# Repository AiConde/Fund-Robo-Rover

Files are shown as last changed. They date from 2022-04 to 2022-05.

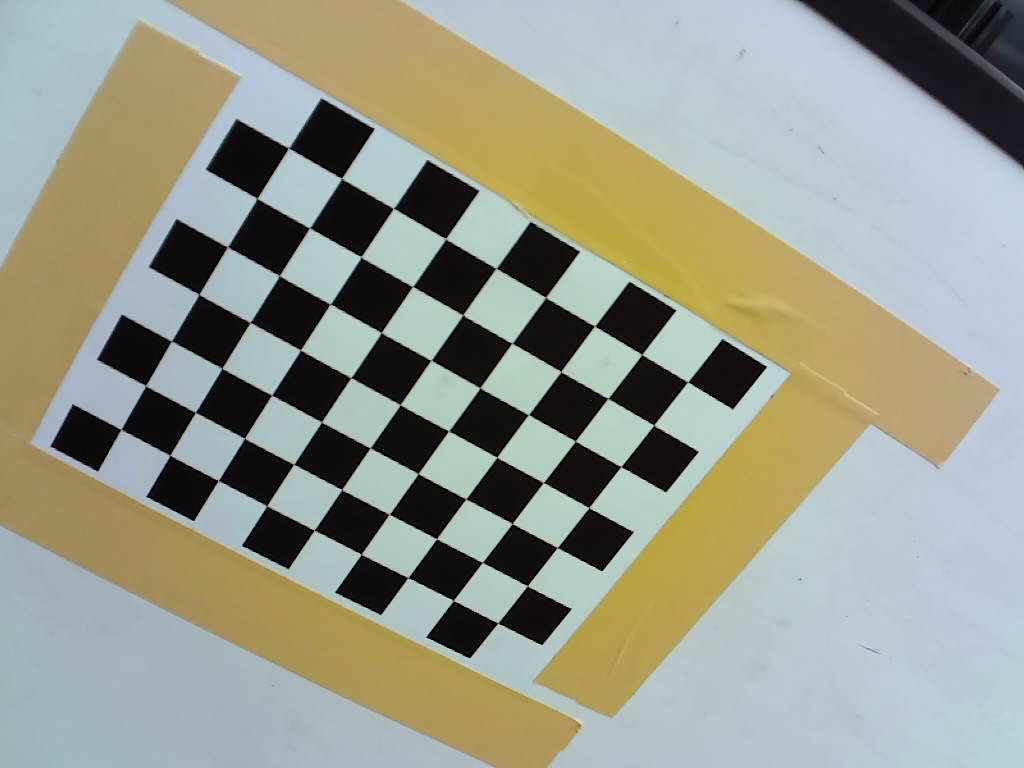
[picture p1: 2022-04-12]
matlab_code/camera_calibration/calib_1024x768/my_photo-11.jpg

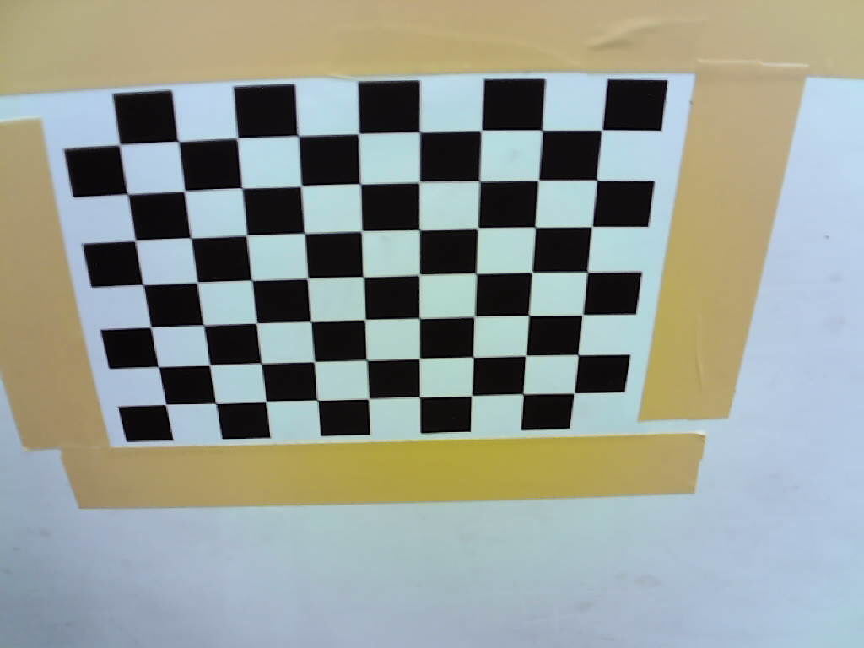
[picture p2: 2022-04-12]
matlab_code/camera_calibration/calib_1024x768/my_photo-2.jpg

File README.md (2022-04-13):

# Fund-Robo-Rover
This repository contains shared files for team 1's final project in Fundamentals of Robotics, Spring 2022.

There are two file categories: CAD files (mostly SOLIDWORKS files) and robot control code (mostly MATLAB files with some ROS mixed in).

The sensor features of the rover are:

LiDAR: 1 Hokuyo URG-005
Sonar: 2 MaxBotix MB1040
Infared: 6 Sharp GP2Y0A02YK0F
Camera: 1 SVPRO 8-megapixel webcam, 5-50 mm focus

Logic is run on an intel NUC running Ubuntu and logic/motor controls are routed through an Arduino Nano connected to a HiLetgo Nano v3.

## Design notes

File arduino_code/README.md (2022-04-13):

Please install "Arduino Mbed OS Nano Boards", "Arduino_LSM9DS1", and "Encoder" in the Arduino library installer.

Attached components:
- Onboard LSM9DS1
- 3x Servos (pan servo, ESC PWM, steering servo)
- 6x Sharp IR (connected to analog pins)
- 2x Sonar (connected to analog pins)
- Hall tacometer (connected to digital pins)

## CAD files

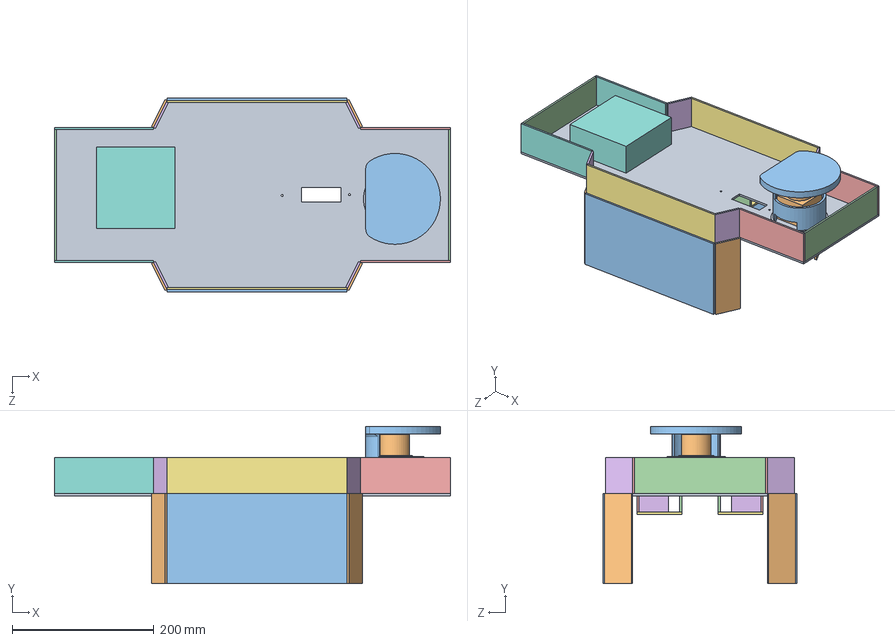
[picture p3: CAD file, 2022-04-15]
CAD files/ShellCAD/ShellAssem.SLDASM
558.8 x 221.9 x 273.0 mm
BasePlate
LowerPanelThin x 4
LowerPanelWide x 2
BatteryCaseShort x 2
BatteryCaseLong x 2
BatteryCaseEnd x 2
NUC
LIDAR_base
LIDAR
LIDAR_top
UpperFront x 2
UpperFrontWall x 2
UpperAngleWallSmall x 4
UpperAngleWallLarge x 2
UpperRearWall x 2
LidarLift

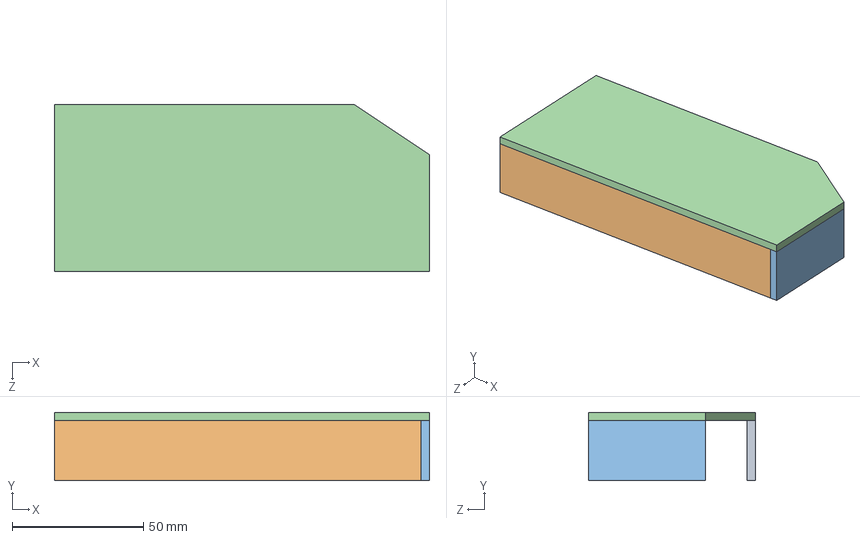
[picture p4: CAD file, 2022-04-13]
CAD files/ShellCAD/BatteryCase/BatteryCaseRAssem.SLDASM
142.9 x 26.0 x 63.5 mm
BatteryCaseShort
BatteryCaseLong
BatteryCaseEnd

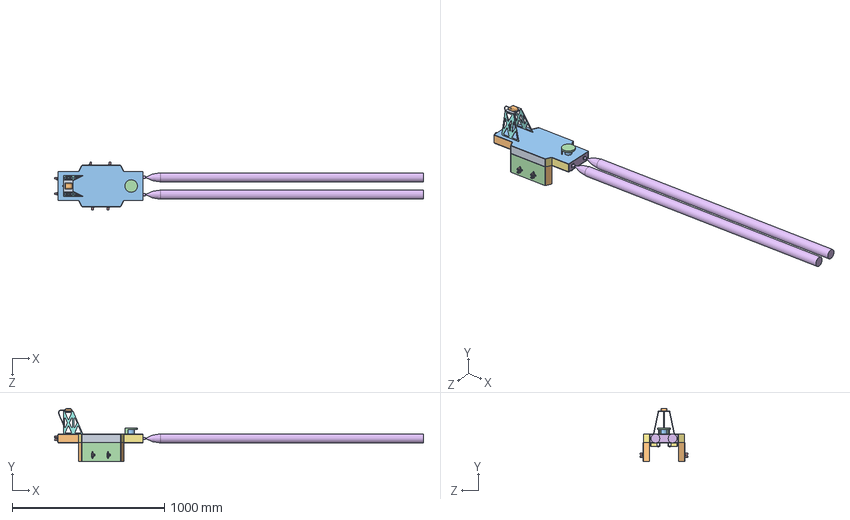
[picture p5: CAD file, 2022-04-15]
CAD files/ShellCAD/WiringHoles/ShellAssem.SLDASM
2425.6 x 350.0 x 316.2 mm
BasePlate
LowerPanelThin x 4
LowerPanelWideLeft
LowerPanelWideRight
BatteryCaseShort x 2
BatteryCaseLong x 2
BatteryCaseEnd x 2
NUC
LIDAR_base
LIDAR
LIDAR_top
UpperRear
UpperFront
UpperFrontWall x 2
UpperAngleWallSmall x 4
UpperAngleWallLarge x 2
UpperRearWall x 2
CoverPlate
LidarLift
OYS-31006 x 6
SENSOR, SONAR, Maxbotix EZ4 x 2
UpperLidCatch x 4
GPSTowerLeg x 2
GPSTowerTop
GPS Antenna

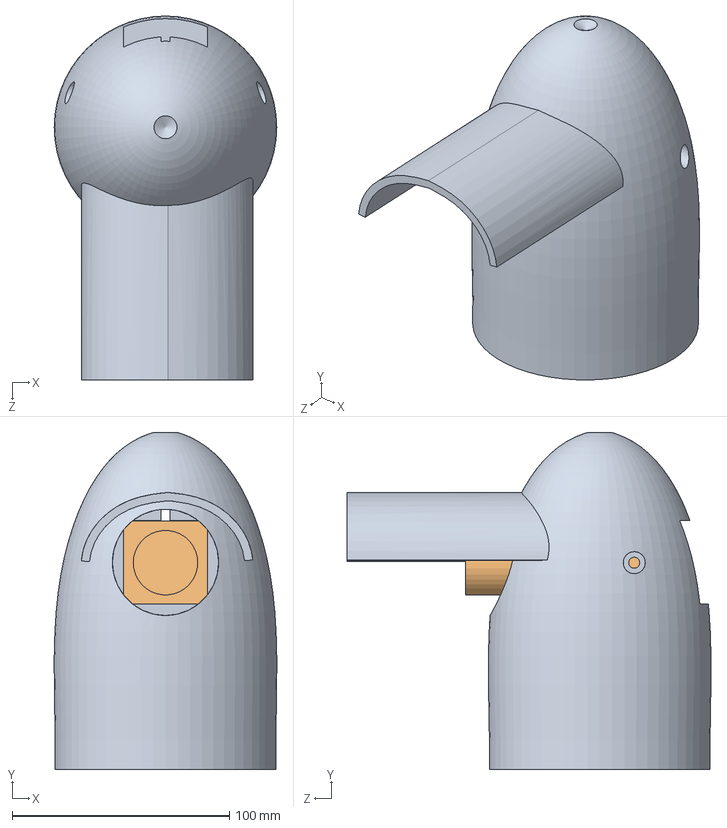
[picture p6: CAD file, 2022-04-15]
CAD files/Assem1.SLDASM
102.5 x 155.3 x 167.6 mm
among_us
camera

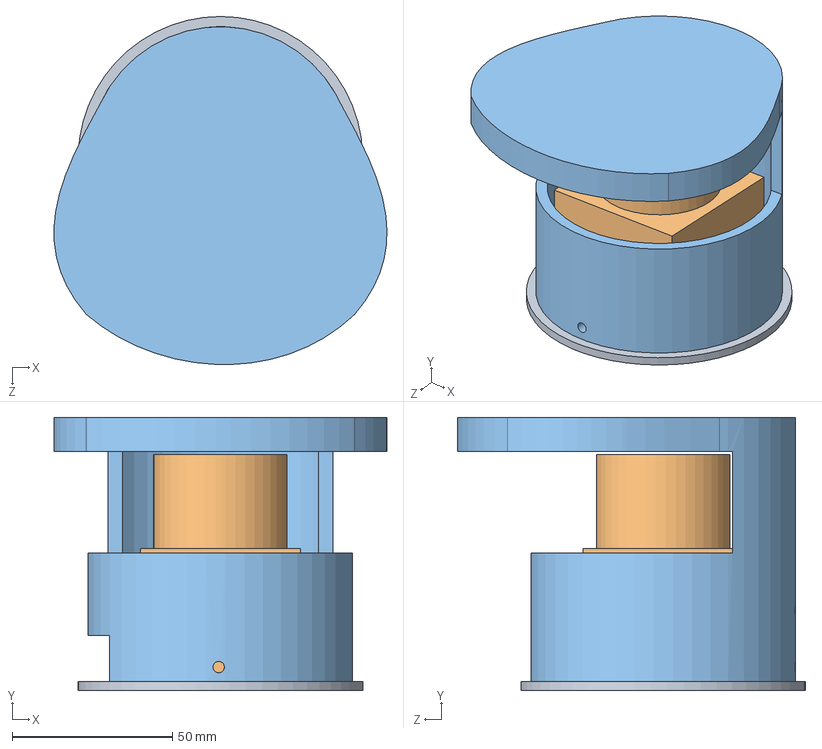
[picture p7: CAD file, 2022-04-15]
CAD files/LIDAR_case.SLDASM
104.0 x 85.3 x 108.7 mm
LIDAR_base
LIDAR
LIDAR_top

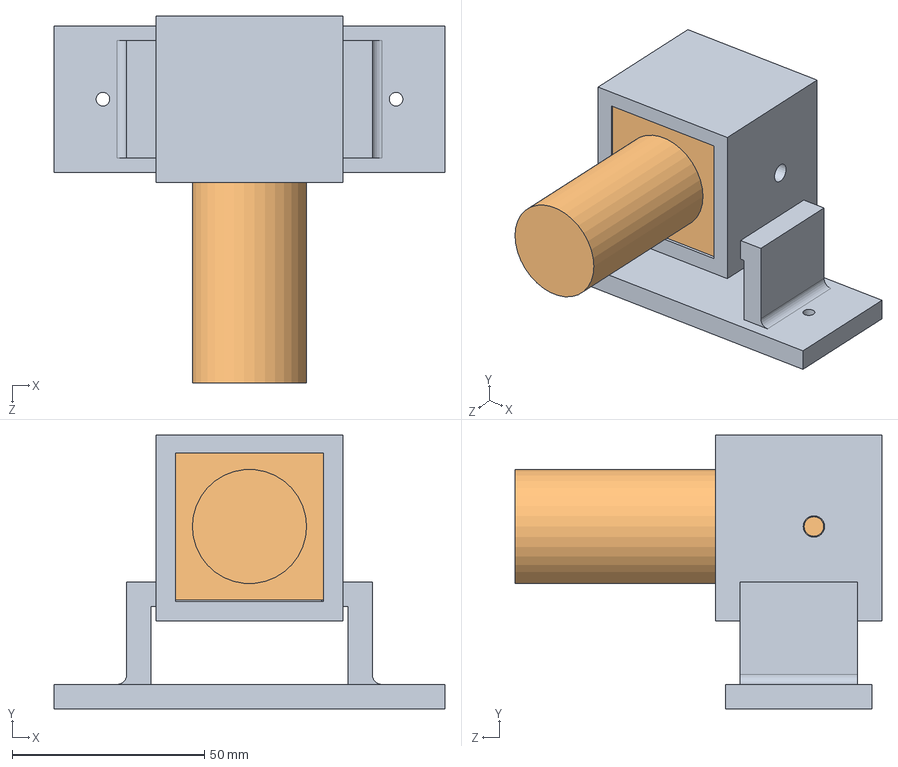
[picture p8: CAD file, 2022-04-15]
CAD files/camer_case.SLDASM
101.6 x 71.2 x 95.5 mm
cam_case
camera

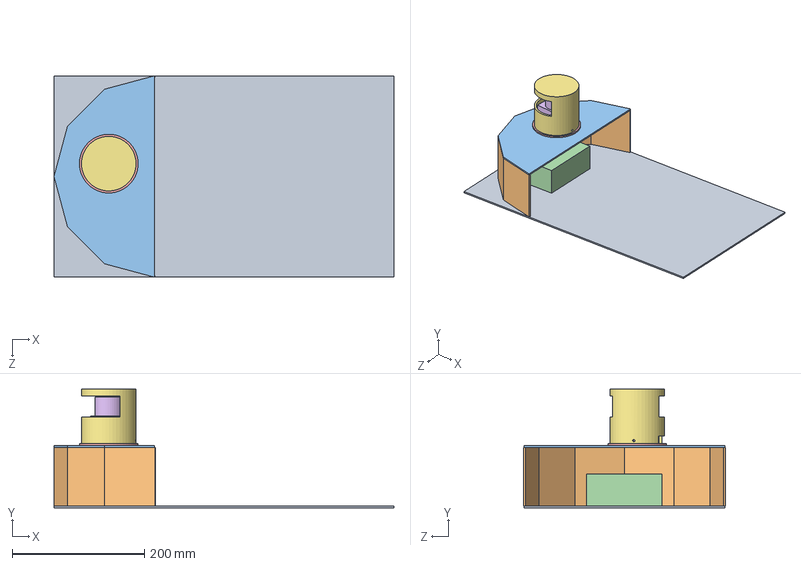
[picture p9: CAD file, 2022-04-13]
CAD files/outershell.SLDASM
514.3 x 179.8 x 304.9 mm
Base
hex_IR x 6
hex_hood
NUC
LIDAR_base
LIDAR
LIDAR_top

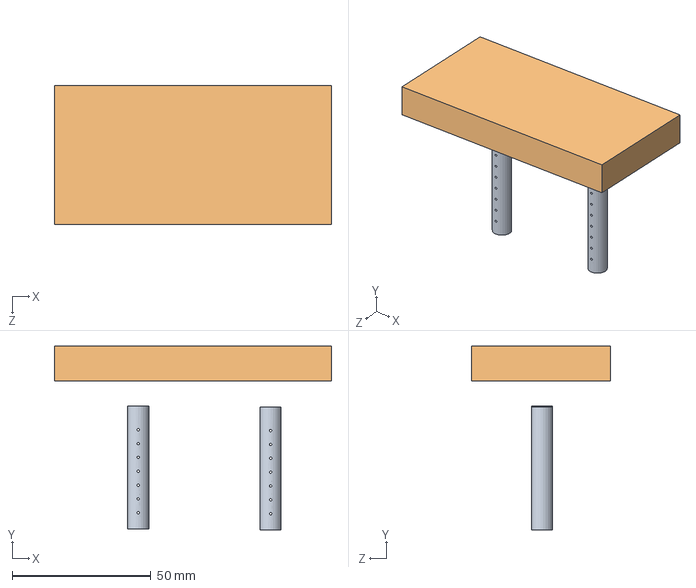
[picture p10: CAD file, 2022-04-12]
CAD files/Attachment.SLDASM
100.0 x 66.4 x 50.0 mm
Attachment Leg x 2
Attachment Plate

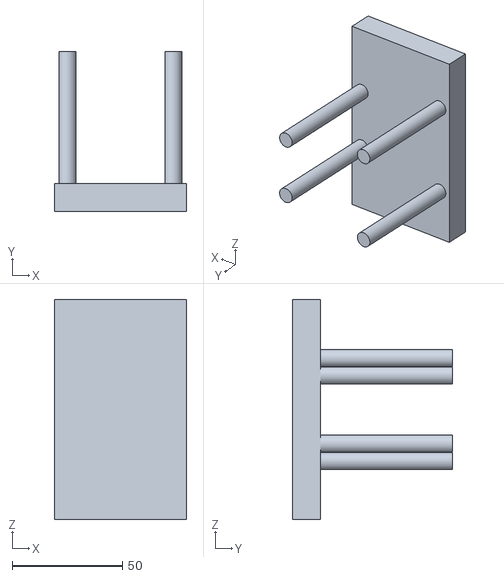
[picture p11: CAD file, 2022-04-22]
CAD files/3D print please/For Dave/Attachment Print.STL
60.0 x 72.7 x 100.0

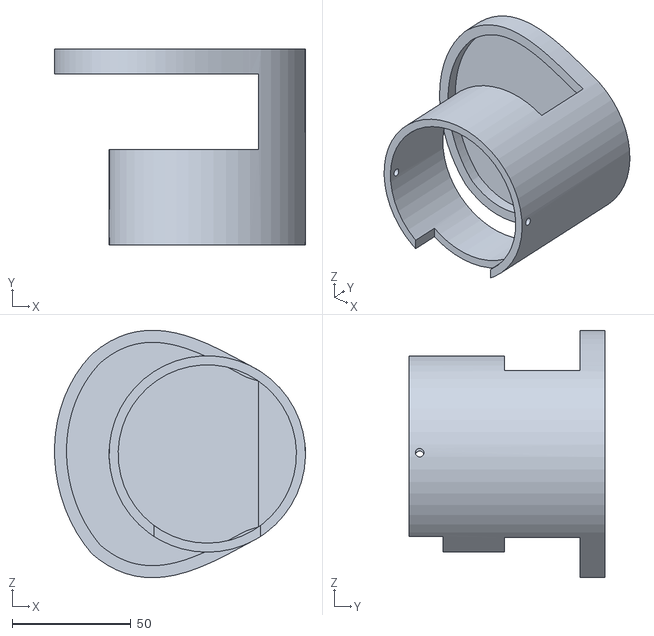
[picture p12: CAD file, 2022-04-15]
CAD files/3D print please/LIDAR_top2-0.STL
105.5 x 82.5 x 104.0

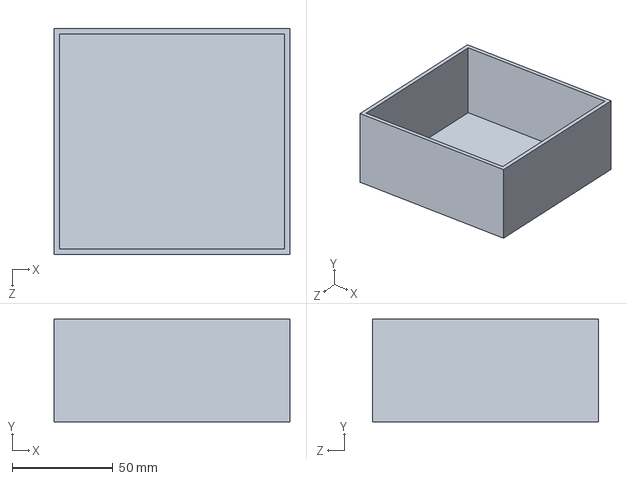
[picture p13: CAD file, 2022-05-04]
CAD files/Nuc Housing Rev 1.SLDPRT
117.3 x 51.1 x 112.5 mm

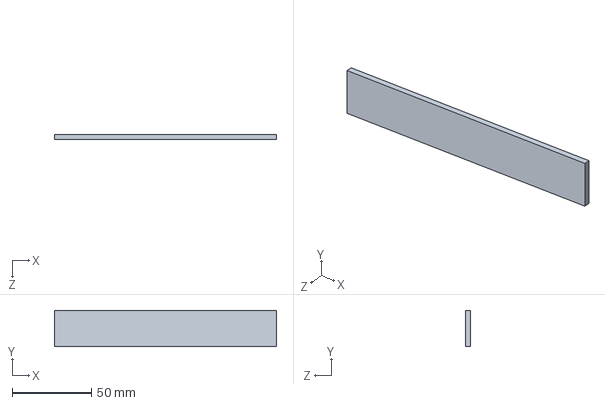
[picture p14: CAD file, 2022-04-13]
CAD files/ShellCAD/BatteryCase/BatteryCaseLong.SLDPRT
139.7 x 22.9 x 3.17 mm

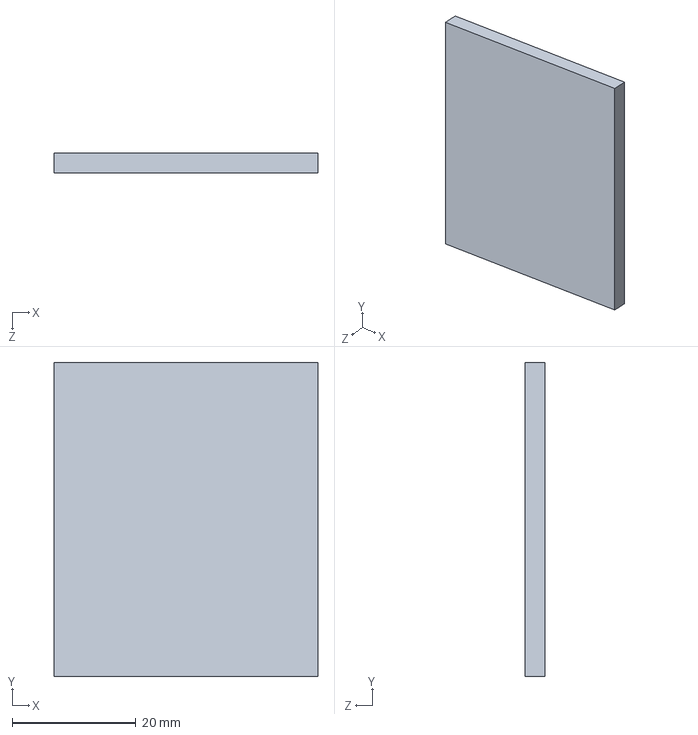
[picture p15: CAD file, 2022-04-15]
CAD files/ShellCAD/WiringHoles/UpperLidCatch.SLDPRT
42.7 x 50.8 x 3.17 mm

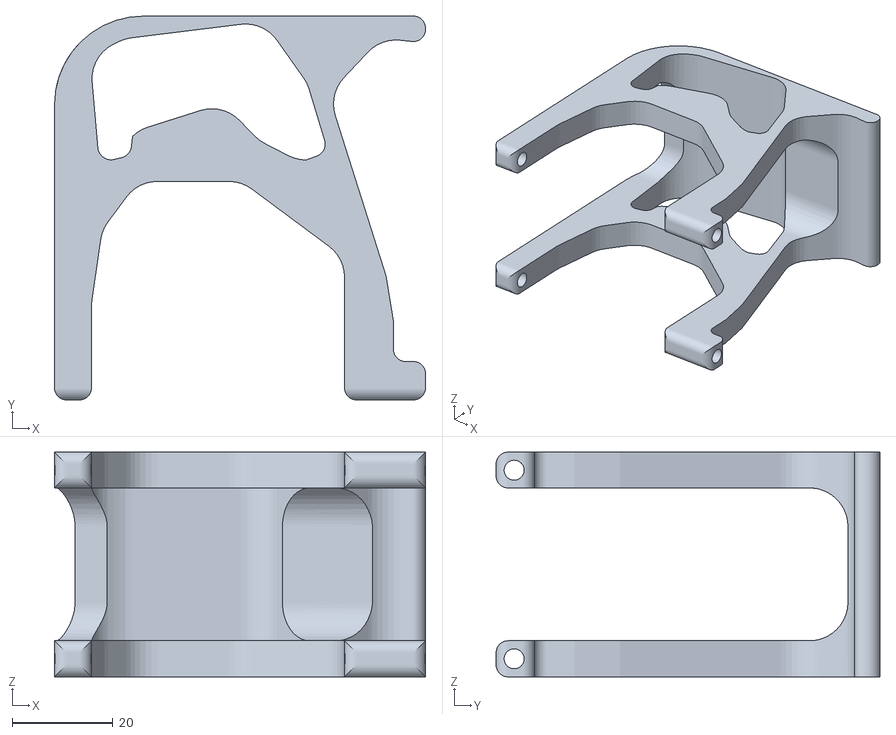
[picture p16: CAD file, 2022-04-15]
CAD files/3D print please/For Dave/frame_adapter.STL
73.7 x 76.2 x 44.6

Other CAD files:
CAD files/ShellCAD/BatteryCase/BatteryCaseLAssem.SLDASM
CAD files/pan_mechanism.SLDASM
CAD files/3D print please/fram adapter.STL
CAD files/Attachment Plate.SLDPRT
CAD files/3D print please/For Dave/Lidar_Case.STL
CAD files/3D print please/For Dave/camera_case.STL
CAD files/3D print please/For Dave/camera_sun-shield.STL
CAD files/3D print please/LIDAR_base.STL
CAD files/3D print please/LIDAR_top.STL
CAD files/3D print please/cam_case.STL
CAD files/Attachment Leg.SLDPRT
CAD files/Base.SLDPRT
CAD files/GPS Antenna.SLDPRT
CAD files/IR.SLDPRT
CAD files/LIDAR.SLDPRT
CAD files/LIDAR_base.SLDPRT
CAD files/LIDAR_top.SLDPRT
CAD files/LIDAR_top_sun.SLDPRT
CAD files/NUC.SLDPRT
CAD files/ShellCAD/BatteryCase/BatteryCaseEnd.SLDPRT
CAD files/ShellCAD/BatteryCase/BatteryCaseShort.SLDPRT
CAD files/ShellCAD/CoverPlate.SLDPRT
CAD files/ShellCAD/WiringHoles/BasePlate.SLDPRT
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

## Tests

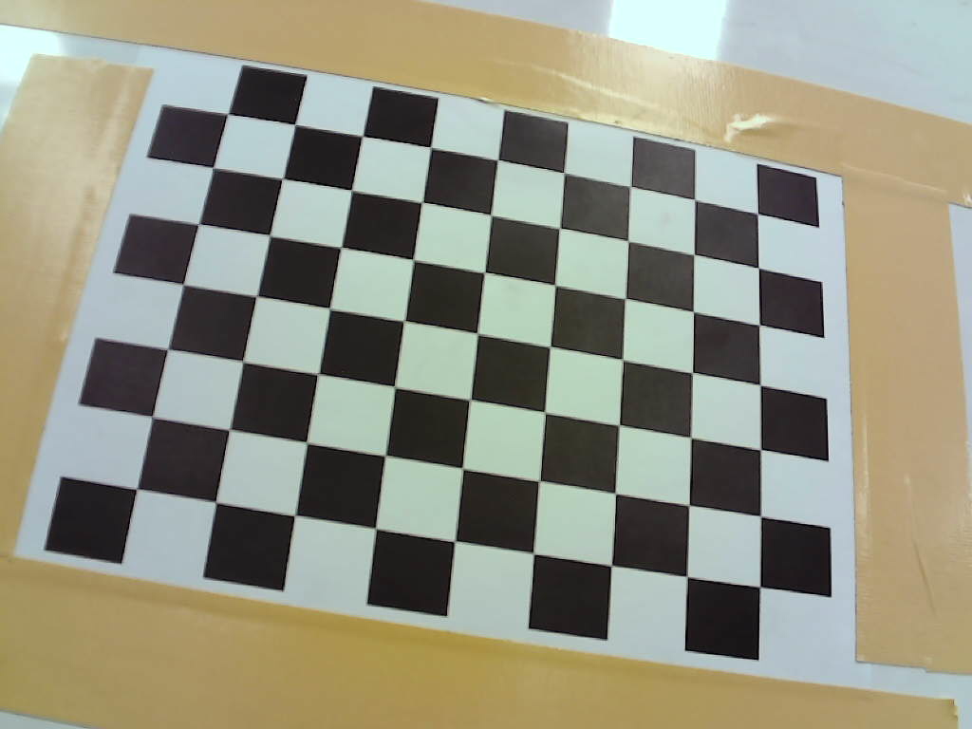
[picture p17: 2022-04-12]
matlab_code/camera_calibration/calib_1024x768/my_photo-3.jpg

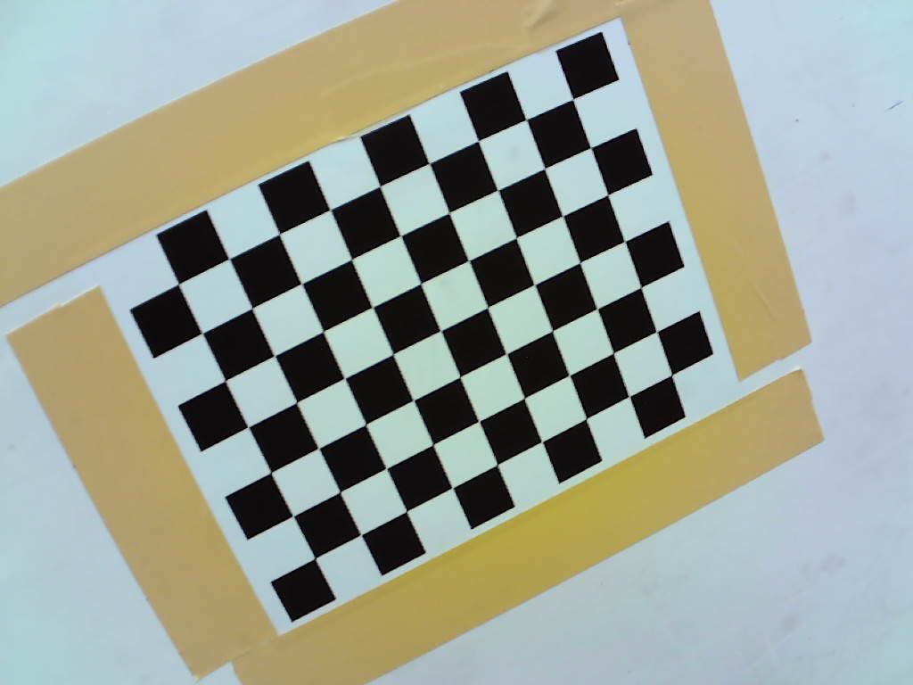
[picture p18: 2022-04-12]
matlab_code/camera_calibration/calib_1024x768/my_photo-23.jpg

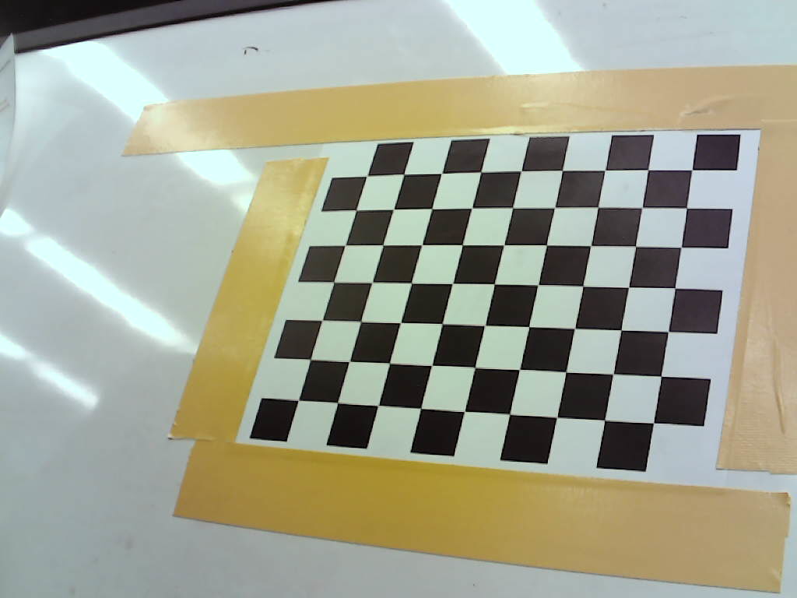
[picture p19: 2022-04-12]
matlab_code/camera_calibration/calib_1024x768/my_photo-10.jpg

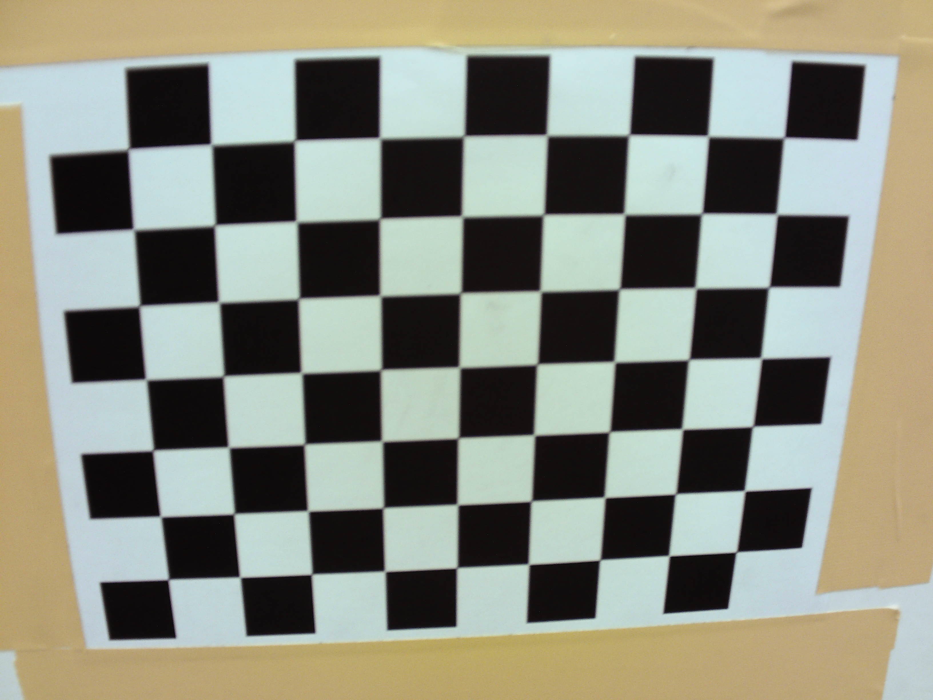
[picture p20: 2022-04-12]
matlab_code/camera_calibration/calib_3268x2448/my_photo-5.jpg

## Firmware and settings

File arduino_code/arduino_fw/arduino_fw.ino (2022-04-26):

#include "imu.h"
#include "typedefs.h"
#include "pindef.h"
#include "led.h"
#include "serial_comms.h"
#include "servos.h"
#include "sharpir.h"
#include "sonar.h"
#include "tacometer.h"

#include <ros.h>
#include <ros/time.h>

#include <std_msgs/UInt32.h>
#include <std_msgs/Int32.h>
#include <std_msgs/Float32.h>
#include <std_msgs/Float32MultiArray.h>
#include <sensor_msgs/Imu.h>
#include <sensor_msgs/MagneticField.h>

bool is_esc_enabled = false;
uint32_t last_esc_cmd_timestamp_ms = 0;
uint32_t esc_cmd_timeout_ms = 1000;

void esc_servo_callback(const std_msgs::Float32 &cmd_msg) {
  is_esc_enabled = true;
  last_esc_cmd_timestamp_ms = millis();
  servos::servos_write(cmd_msg.data, servos::ESC_PWM);
}
void pan_servo_callback(const std_msgs::Float32 &cmd_msg) {
  servos::servos_write(cmd_msg.data, servos::SERVO_PAN);
}
void steer_servo_callback(const std_msgs::Float32 &cmd_msg) {
  servos::servos_write(cmd_msg.data, servos::SERVO_STEER);
}

ros::NodeHandle nh;

ros::Subscriber<std_msgs::Float32> esc_servo_sub("/arduino_cmd/throttle", esc_servo_callback);
ros::Subscriber<std_msgs::Float32> steer_servo_sub("/arduino_cmd/steer", steer_servo_callback);
ros::Subscriber<std_msgs::Float32> pan_servo_sub("/arduino_cmd/pan", pan_servo_callback);

sensor_msgs::Imu imu_msg;
sensor_msgs::MagneticField mag_msg;
std_msgs::Float32MultiArray ir_msg;
std_msgs::Float32MultiArray sonar_msg;
std_msgs::UInt32 tacometer_count;
std_msgs::UInt32 esc_pwm_us;



#define IR_MSG_BUFFER_SIZE 6
#define SONAR_MSG_BUFFER_SIZE 2
float ir_msg_buffer[IR_MSG_BUFFER_SIZE];
float sonar_msg_buffer[SONAR_MSG_BUFFER_SIZE];

ros::Publisher pub_imu("/arduino_data/imu", &imu_msg);
ros::Publisher pub_mag("/arduino_data/magnetometer", &mag_msg);
ros::Publisher pub_ir("/arduino_data/ir_array", &ir_msg);
ros::Publisher pub_sonar("/arduino_data/sonar_array", &sonar_msg);
ros::Publisher pub_tacometer("/arduino_data/tacometer", &tacometer_count);

ros::Publisher pub_escfb("/arduino_data/esc_pwm_us", &esc_pwm_us);



//ir_msg.data_length = 6;

uint32_t loop_start_us_100Hz;
const uint32_t loop_period_us_100Hz = 10000; // 10 ms = 100Hz

uint32_t loop_start_us_10Hz;
const uint32_t loop_period_us_10Hz = 100000; // 100 ms = 10Hz



void setup() {
  analogReadResolution(12);

  Serial.begin(115200);
  nh.getHardware()->setBaud(115200);

  led::setup();
  led::set(false);

  servos::init();
  sharpir::init();
  sonar::init();
  tacometer::init();
  imu::init();
  //serial_comms::init();

  led::set(true);

  nh.initNode();

  for (uint8_t i = 0; i < IR_MSG_BUFFER_SIZE; i++)
    ir_msg_buffer[i] = 0.0f;
  for (uint8_t i = 0; i < SONAR_MSG_BUFFER_SIZE; i++)
    sonar_msg_buffer[i] = 0.0f;

  ir_msg.data = ir_msg_buffer;
  sonar_msg.data = sonar_msg_buffer;
  ir_msg.data_length = IR_MSG_BUFFER_SIZE;
  sonar_msg.data_length = SONAR_MSG_BUFFER_SIZE;

  tacometer_count.data = 0;

  for (uint8_t i = 0; i < 9; i++) {
    imu_msg.orientation_covariance[i] = 0.f;
    imu_msg.angular_velocity_covariance[i] = 0.f;
    imu_msg.linear_acceleration_covariance[i] = 0.f;
  }
  imu_msg.orientation_covariance[0] = -1.f;
  imu_msg.angular_velocity_covariance[0] = -1.f;
  imu_msg.linear_acceleration_covariance[0] = -1.f;

  imu_msg.orientation.x = -1.f;
  imu_msg.orientation.y = -1.f;
  imu_msg.orientation.z = -1.f;
  imu_msg.orientation.w = -1.f;

  imu_msg.angular_velocity.x = -1.f;
  imu_msg.angular_velocity.y = -1.f;
  imu_msg.angular_velocity.z = -1.f;

  imu_msg.linear_acceleration.x = -1.f;
  imu_msg.linear_acceleration.y = -1.f;
  imu_msg.linear_acceleration.z = -1.f;

  for (uint8_t i = 0; i < 9; i++) {
    mag_msg.magnetic_field_covariance[i] = 0.f;
  }
  mag_msg.magnetic_field.x = -1.f;
  mag_msg.magnetic_field.y = -1.f;
  mag_msg.magnetic_field.z = -1.f;

  loop_start_us_10Hz = get_time_micros_safe();
  loop_start_us_100Hz = loop_start_us_10Hz;

  nh.advertise(pub_imu);
  nh.advertise(pub_mag);
  nh.advertise(pub_sonar);
  nh.advertise(pub_ir);
  nh.advertise(pub_tacometer);
  nh.advertise(pub_escfb);

  nh.subscribe(esc_servo_sub);
  nh.subscribe(steer_servo_sub);
  nh.subscribe(pan_servo_sub);


}

void loop_100hz() {
  sharpir::read_loop_100hz();
  sonar::read_loop_100hz();
  imu::read_loop_1khz();



  imu::imu_reading_t imu_reading_buf;


  imu::get_readings_raw(&imu_reading_buf);


  // Convert deg/s to rad/s
  imu_msg.angular_velocity.x = imu_reading_buf.gyro_x * 1.0f;
  imu_msg.angular_velocity.y = imu_reading_buf.gyro_y * 1.0f;
  imu_msg.angular_velocity.z = imu_reading_buf.gyro_z * 1.0f;

  // Convert gees to m/s
  imu_msg.linear_acceleration.x = imu_reading_buf.accel_x*1.0f;
  imu_msg.linear_acceleration.y = imu_reading_buf.accel_y*1.0f;
  imu_msg.linear_acceleration.z = imu_reading_buf.accel_z*1.0f;

  // Convert gauss to tesla
  mag_msg.magnetic_field.x = imu_reading_buf.mag_x * 0.000001f;
  mag_msg.magnetic_field.y = imu_reading_buf.mag_y * 0.000001f;
  mag_msg.magnetic_field.z = imu_reading_buf.mag_z * 0.000001f;

  tacometer::tacometer_readings_t taco_readings;
  tacometer::get_count(&taco_readings);
  tacometer_count.data = taco_readings.tacometer_count;


  pub_imu.publish(&imu_msg);
  pub_mag.publish(&mag_msg);

  pub_escfb.publish(&esc_pwm_us);


}

void loop_10hz() {
  sharpir::sharpir_reading_t sharpir_reading_buf;
  sonar::sonar_reading_t sonar_reading_buf;
  sharpir::get_filtered_readings(&sharpir_reading_buf);
  sonar::get_filtered_readings(&sonar_reading_buf);
  ir_msg_buffer[0] = sharpir_reading_buf.sharpir1_voltage;
  ir_msg_buffer[1] = sharpir_reading_buf.sharpir2_voltage;
  ir_msg_buffer[2] = sharpir_reading_buf.sharpir3_voltage;
  ir_msg_buffer[3] = sharpir_reading_buf.sharpir4_voltage;
  ir_msg_buffer[4] = sharpir_reading_buf.sharpir5_voltage;
  ir_msg_buffer[5] = sharpir_reading_buf.sharpir6_voltage;

  sonar_msg_buffer[0] = sonar_reading_buf.sonar1_voltage;
  sonar_msg_buffer[1] = sonar_reading_buf.sonar2_voltage;
  pub_sonar.publish(&sonar_msg);
  pub_ir.publish(&ir_msg);
  
  pub_tacometer.publish(&tacometer_count);

  if (is_esc_enabled) {
    if (millis() > last_esc_cmd_timestamp_ms + esc_cmd_timeout_ms) {
      is_esc_enabled = false;
      servos::servos_write(0.5, servos::ESC_PWM);
    }
  }
}

void loop_1khz() {

}

void loop() {
  if (period_elapsed_micros_safe(loop_start_us_100Hz, loop_period_us_100Hz)) {
    loop_start_us_100Hz = get_time_micros_safe();
    loop_100hz();
  }

  if (period_elapsed_micros_safe(loop_start_us_10Hz, loop_period_us_10Hz)) {
    loop_start_us_10Hz = get_time_micros_safe();
    loop_10hz();
  }

  nh.spinOnce();
}

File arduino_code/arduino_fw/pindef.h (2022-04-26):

#pragma once

#define NUM_SHARPIR 6
#define NUM_SONAR 2

#define SHARPIR1_PIN A0
#define SHARPIR2_PIN A1
#define SHARPIR3_PIN A2
#define SHARPIR4_PIN A3
#define SHARPIR5_PIN A4
#define SHARPIR6_PIN A5

#define SONAR1_PIN A6
#define SONAR2_PIN A7

#define STEER_SERVO_PIN D5
#define ESC_PWM_PIN D3
#define PAN_SERVO_PIN D7

#define STEER_SERVO_MIN_PULSE 1000
#define STEER_SERVO_MAX_PULSE 2000

#define ESC_PWM_MIN_PULSE 1000
#define ESC_PWM_MAX_PULSE 2000

#define PAN_SERVO_MIN_PULSE 1000
#define PAN_SERVO_MAX_PULSE 2000

#define TACOMETER_INPUT_PIN D8
#define TACOMETER_DUMMY_PIN D9

#define LED_PIN LED_BUILTIN

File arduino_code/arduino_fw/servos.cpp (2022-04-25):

#include "servos.h"
#include <Servo.h>
#include <std_msgs/UInt32.h>


extern std_msgs::UInt32 esc_pwm_us;

namespace servos {

    Servo esc_pwm_servo;
    Servo pan_servo;
    Servo steer_servo;

    void init() {
        esc_pwm_servo.attach(ESC_PWM_PIN);
        pan_servo.attach(PAN_SERVO_PIN);
        steer_servo.attach(STEER_SERVO_PIN);
    }

    void servos_write(float value, servos_t servo) {
        uint32_t pwm_us_min;
        uint32_t pwm_us_max;
        switch(servo) {
            case ESC_PWM:
                pwm_us_min = ESC_PWM_MIN_PULSE;
                pwm_us_max = ESC_PWM_MAX_PULSE;
                break;
            case SERVO_PAN:
                pwm_us_min = PAN_SERVO_MIN_PULSE;
                pwm_us_max = PAN_SERVO_MAX_PULSE;
                break;
            case SERVO_STEER:
                pwm_us_min = STEER_SERVO_MIN_PULSE;
                pwm_us_max = STEER_SERVO_MAX_PULSE;
                break;
            default:
                pwm_us_min = 1000;
                pwm_us_max = 2000;

        }

        float value_clamped = math_clamp<float>(value, 0.0f, 1.0f);

        float out_us_f32 = math_map<float>(value, 0.0f, 1.0f, (float) pwm_us_min, (float) pwm_us_max);
        uint32_t out_us_u32 = (uint32_t) roundf(out_us_f32);
        uint32_t servo_pwm_us = math_clamp<uint32_t>(out_us_f32, pwm_us_min, pwm_us_max);

        switch(servo) {
            case ESC_PWM:
                esc_pwm_us.data = servo_pwm_us;
                esc_pwm_servo.writeMicroseconds(servo_pwm_us);
                break;
            case SERVO_PAN:
                pan_servo.writeMicroseconds(servo_pwm_us);
                break;
            case SERVO_STEER:
                steer_servo.writeMicroseconds(servo_pwm_us);
                break;
            default: break;
        }
    }

    void deinit() {
        esc_pwm_servo.detach();
        pan_servo.detach();
        steer_servo.detach();
    }
}

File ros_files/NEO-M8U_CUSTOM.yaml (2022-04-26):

# Unique Parameters for Ublox ROS driver for the NEO-M8U:
# This configuration file was written following and referencing the UBX-13002887 document.

debug: 1
# save:
#   mask: 3103    Uncommenting the above saves this configuration file to the non-volatile flash. 
#   device: 4     Unnecessary to remove since ROS runs this script every time it launches

# Sub-Section 0 PRT - Port, USB, UART, SPI and DDC settings

device: /dev/ttyACM0

uart1:
  baudrate: 115200
  in: 1               # UBX Configuration Inputs Only                
  out: 2              # NMEA Outputs Only
  
frame_id: gps


# Sub-Section 1 MSG - Message Settings (enable/disable, update rate)
subscribe:
  all: true
  aid:
    all: false

# Sub-Section 2 INF - Information Output Settings (Errors, Warnings, Notice, Test etc.)
inf:
  all: true
      
publish:
  all: true
  hnr:
    pvt: true
  esf:
    all: true
    ins: true
    meas: true
    raw: true
    status: true
  nav:
    all: true
    sat: true
    status: true
    pvt: true
    att: true

# Sub-Section 3 NAV - Settings for Navigation Parameters, Receiver Datum, Measurement and Navigation Rate, SBAS, NMEA and
                     # Time mode
                     
# NAV5Parameters
dynamic_model: 0    # Zero is for Portable Devices
fix_mode: 3         # Auto 2D/3D Fix Mode. 3D = Altitude + Long. + Lat., 2D = Long. + Lat.
                    # 2D Requires 3 Satellites, 3D Requires 4 Satellites
                    # 3D takes precedent unless only 3 visible satellites
dr_limit: 0


# NAVX5 Parameters


# DAT Parameters
dat:
  set: false

# RATE Parameters
rate: 5             # Measurement rate in Hz which is 1 relative to nav_rate
nav_rate: 5         # Number of Measurement cycles
use_adr: true
# Note that for NEO-M8U which is a UDR device 1 is reccommended for nav_rate

# SBAS Parameters
sbas:
  usage: 1          # Using SBAS as a Geo ranging source i.e. Augmenting satellites for better coverage
                     
# NMEA Parameters
nmea:
  set: true
  version: 65         # Hexadecimal for NMEA version 4.1 supported by NEO-M8U. 4.1 must be used to support Galileo and is set here!!
  num_sv: 8           # Number of satellite's that can spit information from each TalkerID (i.e. GN = Glonass talker ID)
  sv_numbering: 1
  compat: true
  consider: true
  limit82: true
  high_prec: true
  filter:
    pos: false
    msk_pos: false
    time: false
    date: false
    gps_only: false
    track: false
  gnssToFilter:       # True = Disables reporting of those satellites, False = Enables Reporting
    gps: false
    sbas: false
    qzss: true
    glonass: true
    beidou: false
  main_talker_id: 1   # Sets the main talker ID to GPS
  gsv_talker_id: 1    # Sets the default main talker ID to GPS
  bds_talker_id: [0,0]
  
# TMODE2 Parameters
         
# Sub-Section 4 RXM - GNSS Settings, Power Mode Settings, Time Pulse Settings, Jamming/Interference Monitor Settings
# GNSS Parameters
gnss:
  gps: true
  glonass: false
  beidou: true
  galileo: true
  qzss: false
  sbas: true
  imes: false
  
#Sub-Section 9 RINV - Remote Inventory Configuration


# Sub-Section 10 ANT - Antenna Configuration


# Sub-Section 11 LOG - Logging Configuration


# Sub-Section 12 FTS - Disciplining Configuration. Only applicable to th eTime & Frequency Sync product

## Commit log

2022-04-11 Some class stubs for misc hardware used - Rover, Lidar, Camera, Sonar, SharpIR, etc, as well as some boilerplate code for servo control + specific implementations for steer+pan+throttle servos
2022-04-11 Add boilerplate LIDAR code, stubs for localization engine
2022-04-11 Add static utils class for misc stuff, add prelim camera image acq + april tag detection/processing
2022-04-12 cad files whoooo
    [Base.SLDPRT, hex_IR.SLDPRT, outershell.SLDASM]
2022-04-12 BCT Lidar Code
    Lidar Object-Rec Sensing Code
2022-04-12 Added calibration images+params, as well as april tag test
2022-04-12 more CAD (all sensors added)
    [Base.SLDPRT, GPS Antenna.SLDPRT, IR.SLDPRT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]
2022-04-12 Attachment CAD
    [Attachment Leg.SLDPRT, Attachment Plate.SLDPRT, Attachment.SLDASM]
2022-04-12 Minor work on Lidar and SharpIR files
    Not super major
2022-04-12 cad update + gcode for 3D print
    [LIDAR.SLDPRT, LIDAR_base.SLDPRT, LIDAR_base.STL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]
2022-04-13 Repositioned Shell Cad
2022-04-13 Battery Case Components
    [BatteryCaseEnd.SLDPRT, BatteryCaseLAssem.SLDASM, BatteryCaseLong.SLDPRT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]
2022-04-13 In-Progress Rover Shell
    [BasePlate.SLDPRT, CoverPlate.SLDPRT, LidarLift.SLDPRT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]
2022-04-13 camera mount + holes on top part of frame for camera/LIDAR
    [BasePlate.SLDPRT, CoverPlate.SLDPRT, ShellAssem.SLDASM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]
2022-04-13 Moved some files, added Arduino code
2022-04-13 Added class to pull Lidar data from ROS
2022-04-14 Added working lidar ROS integration
2022-04-14 updated camera cover, lidar cover
    [Assem1.SLDASM, CoverPlate.SLDPRT, LIDAR_case.SLDASM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]
2022-04-14 Added Sensor Mounts
    [BasePlate.SLDPRT, CoverPlate.SLDPRT, GPSTowerLeg.SLDPRT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]
2022-04-15 Attachment Changes
    [Attachment Leg.SLDPRT, Attachment Plate.SLDPRT]
2022-04-15 Add test Rosbag of LIDAR data
2022-04-16 Working ROS integration with Arduino!
    Read from:
    /arduino_data/imu
    /arduino_data/ir_array
    /arduino_data/sonar_array
    /arduino_data/tacometer
    Write to:
    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
2022-04-17 Add ROS drivers for GPS, Arduino, and finish driver for camera
2022-04-22 Add support for reading Arduino LSM9DS1 magnetometer, and correct units published by Arduino.
    [arduino_fw.ino]
2022-04-22 Attachment Plan B
    [Attachment Plate.SLDPRT, Attachment Print.STL]
2022-04-22 Boosted Arduino serial communications speed, and added launch script for ROS nodes
2022-04-25 Make changes to Arduino script for servos, added teleop test drive script and joystick interface
2022-04-25 imu testing
2022-04-25 commenting Arduino_ROS.m and other stuff
2022-04-26 update with imu calibration method
2022-04-26 calibration waitfor
2022-04-26 Update arduino code w/ pinmappings + add tacometer zeroing function to Arduino class
2022-04-29 WIP adding camera settings to Camera_ROS
2022-05-02 Adding test odometry data, changed geometry classes for speed
    [data.csv, down_hall_and_back.csv, hard_left_turn.csv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]
2022-05-02 Add variable timestep to odometry
2022-05-02 Add CalibrateGyroCommand
2022-05-02 Add drivetraincontroller - open loop only now
2022-05-03 NuC Housing
    [Nuc Housing Rev 1.SLDPRT]
2022-05-03 re fixed transform_by after a heated argument
